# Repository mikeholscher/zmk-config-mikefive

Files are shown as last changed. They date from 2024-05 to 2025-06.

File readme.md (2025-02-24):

# mikefive, a Kailh PG1316S keyboard

Welcome to my repo about my mikefive keyboard! 

It's wireless and five millimeters thick. Here's a picture of it:

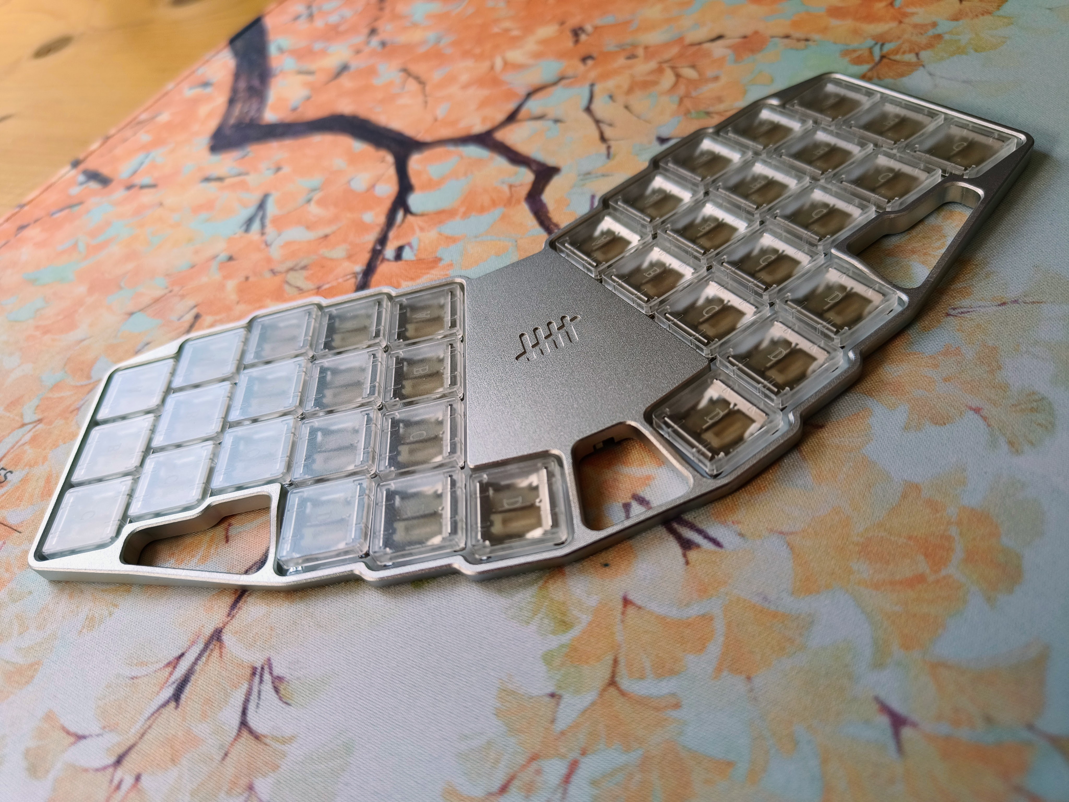
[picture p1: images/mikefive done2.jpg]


The keyboard above is completely custom-designed around Kailh PG1316S switches. 
These switches I got unexpectedly offered by Kailh when ordering other stuff in early 2024. 
I think this build sparked some ultra-low enthusiasm in the community as multiple shops are now carrying them. Go build! 

## Where are the files?!

Sorry. You won't find files or info to build the keyboard yourself here, yet. 

You will only find the ZMK config files for the custom shield, my current keymap, and a custom json for [ZMK Keymap Editor](https://nickcoutsos.github.io/keymap-editor/). 
Most commits here will probably be me updating my keymap :)

Maybe I was a fool to show it to the world already, while I only built a single prototype. 
Because, like with most first prototypes, I found stuff that needs to be improved before other people start building. 
Next to that, another unexpected opportunity arose, which I will definitely scream from the rooftops about when it's more concrete...

## Devlog

Find all noteworthy project developments here. 

I will update this page when there is news, and post on r/ergomechkeyboards or r/olkb too.

### 2025-02-24 I uploaded the keycap files!
You can now find the keycap STEP files in the [keycap folder](/files/custom-keycaps). Don't forget to read the readme in that folder.

### 2024-10-26 I made custom keycaps for the PG1316S switch!
You can read all about in this [Reddit post](https://www.reddit.com/r/ErgoMechKeyboards/comments/1gcibfw/custom_keycaps_for_the_ultralow_kailh_pg1316s/), where I made a write-up in the comments if you would like to read about all the details. I resin-printed them myself. The CAD models will be on this site soon so everybody can print them, after I verified they also fit well using when ordering them from a commercial print service.

Small update: I received a small batch of my keycap prints from JLC, but they have more play to them than my own, and I don't want people to be disappointed when printing my caps. Tolerances are very small on this cap and switch combination. Stay tuned for updates! I am working on it.

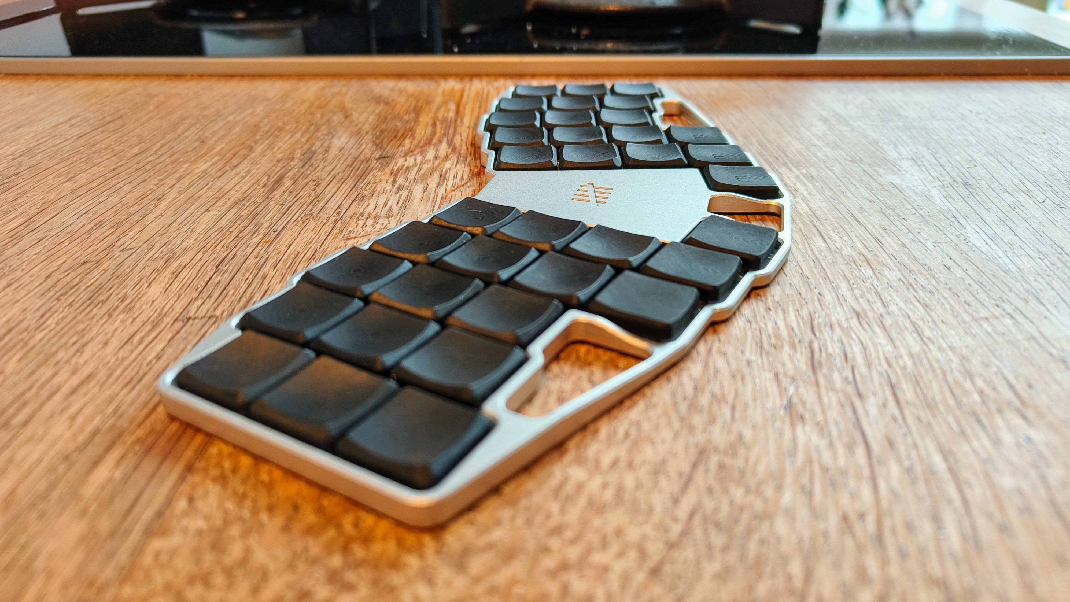
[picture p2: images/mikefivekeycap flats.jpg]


### 2024-07-18 Introducing the even smaller PG1316M, 3D CAD also available!
I was informed by a Reddit member about the existence of the PG1316M. Yes, an M instead of an S at the end. This is a lower height switch, often used as Fn-row keys. I don't have a physical sample yet, but based on the keycap size in CAD, I think the keycap size will be around 16x12mm, compared to the 16x16mm PG1316S. I learned from Kailh, that these will also become available! Again, I am free to share the 3D CAD file, really awesome! You can also find the PDF spec sheet in the folder, as this M version does not seem to be on their website yet. I think I will soon add the KiCad footprint for the PG1316M as well!

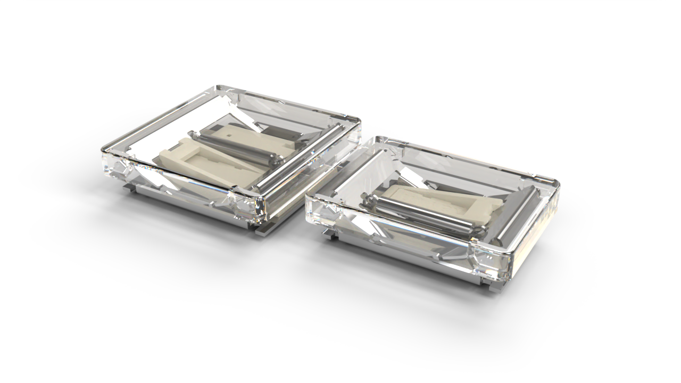
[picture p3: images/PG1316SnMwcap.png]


### 2024-07-16 3D CAD file of PG1316S switch now available!
I received a lot of questions about the availability of a 3D CAD file of the switch and keycap of the PG1316S. Well, I asked Kailh if I could share, and I can! You can find it in the [files folder](/files). I also used the switch model to render images like below and select matching materials before I had the prototype produced. NOTE: This is the original 3D CAD file I received from Kailh. I noticed the switch dimensions are spot-on and the inside of the keycap is too but the outside of the keycap is too small. In reality, the keycap is 16.25mm vertically and 16.05mm horizontally.

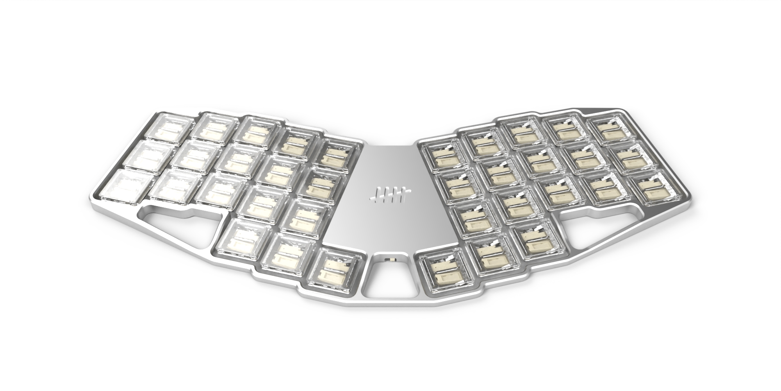
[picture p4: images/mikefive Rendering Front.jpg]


### 2024-06-19 Lighter switches are installed!
I received the lighter prototype switches from Kailh and installed them in the mikefive. They feel much better and are a lot more quiet. I uploaded a small video update on [Reddit](https://www.reddit.com/r/olkb/comments/1djruze/new_lighter_kailh_pg1316s_switches_in_the_mikefive/). I am planning on making an extensive video update soon, with much more news to share!

### 2024-05-26 KiCad footprint now available!
I received a message from someone that was able to order some switches, and asked if I could share the footprint. The KiCad 8.0 footprint is in the [files folder](/files), and looks like this:

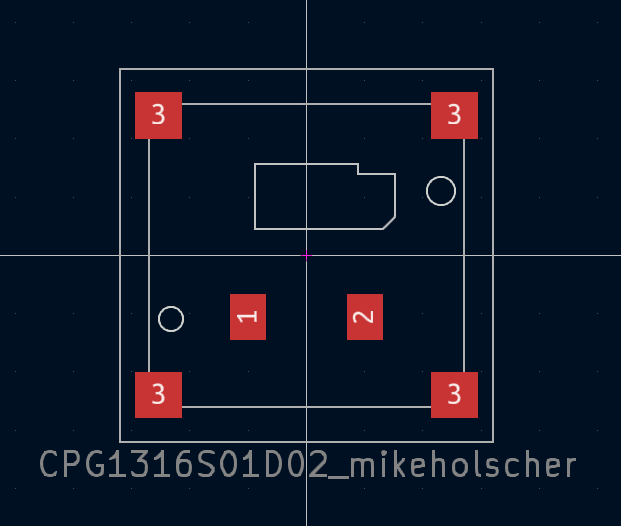
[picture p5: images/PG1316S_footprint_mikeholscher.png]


Some explanation:
- The outer, biggest square is the 16x16mm keycap.
- The slighty smaller square is the switch 'frame' size.
- The two small circles are holes for the allignment pins on the switch.
- Pads 1 and 2 are the switch pads.
- Pads 3 are the SMD mounting points for the switch frame. NOTE: I placed vias in these pads in the PCB to give the switch a more secure connection to the PCB. (I hope) this way the switch connects to both sides of the PCB instead of only the top layer. I connected all pads 3 to GND in the switch diagram and schematic.
- The weird shape in the top half is the available space under the switch for components. I placed my diodes there in the mikefive.

Kailh also made a [product page](https://www.kailhswitch.com/mechanical-keyboard-switches/kailh-ultra-thin-notebook-switch.html) for the PG1316S switch, including [spec sheet](https://www.kailhswitch.com/uploads/15927/files/CPG1316S01D02-data-sheet.pdf?rnd=569) where I based the footprint on. I did some further measurements on the physical switch to complete some details such as the space underneath.

### 2024-05-06 kbd.news reposted!
kbd.news was kind enough to [repost](https://kbd.news/Mikefive-a-Kailh-PG1316S-keyboard-2366.html) my Reddit post on their website!

### 2024-04-28 Hello world :)
After completing the build on Wednesday 24th of April and working with it for a couple days, I decided to make a [post](https://www.reddit.com/r/ErgoMechKeyboards/comments/1cfg3vr/mikefive_a_kailh_pg1316_keyboard/) on r/ergomechkeyboards. 
It became a really long write-up, as I wanted to share as many details as possible.
Thank you all for your flattering replies! They really gave me energy to continue the project and make sure the keyboard will eventually get in the hands of people that want it.

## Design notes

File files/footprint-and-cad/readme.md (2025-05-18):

This space will get some more info about footprints later. 

Note:
I have had good experience with using 0.8mm vias in the switch contact pads and 0.6mm vias in the switch mounting pads. I have the feeling they are easier sucked down to the PCB. 
Some solderpaste will leak onto your hotplate if you put big vias in the pads, and I was warned about possible damage to the hotplate, but so far it seems easy to clean on my Miniware MHP30 and PCB with IPA.
The original specsheet also shows holes in the pads, which might be for a reason. On mikefive I skipped these vias to get a fully contact free bottom, which is also worth something.

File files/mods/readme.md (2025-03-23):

# Kailh PG1316S mods
You just built your first PG1316S keyboard. You spent hours and hours making all of your switches work on your PCB, and then you start typing. Dang, these switches sure feel and sound different. And then you find out your PG1316S doubles as a musical rhythm instrument when you shake it.

No worries. I got you covered. All you need to make your fresh PG1316S keyboard sound and feel a lot better is here :)

I spend a good chunk of time trying to solve these issues by making custom 3D-printed keycaps, which work well to eliminate rattle and improve the sound. But dimensional tolerances are very tight, and these caps are not the easiest to print. I wanted a quick solution that could be used to improve the stock switch and keycap without much effort. The result was two 'papermods', which anybody with a pair of scissors and a piece of paper can do. 

## Papermod1
The papermod1 is just a rectangular piece of paper measuring 13.8x12.7mm that eliminates the play between PG1316S switch and the stock keycap and causes the rattle. This makes the switch feel more robust and silent. Just put it under the keycap as shown in the image, and BAM, instant improvement. Try different thicknesses of paper or even different materials and see what you like best.

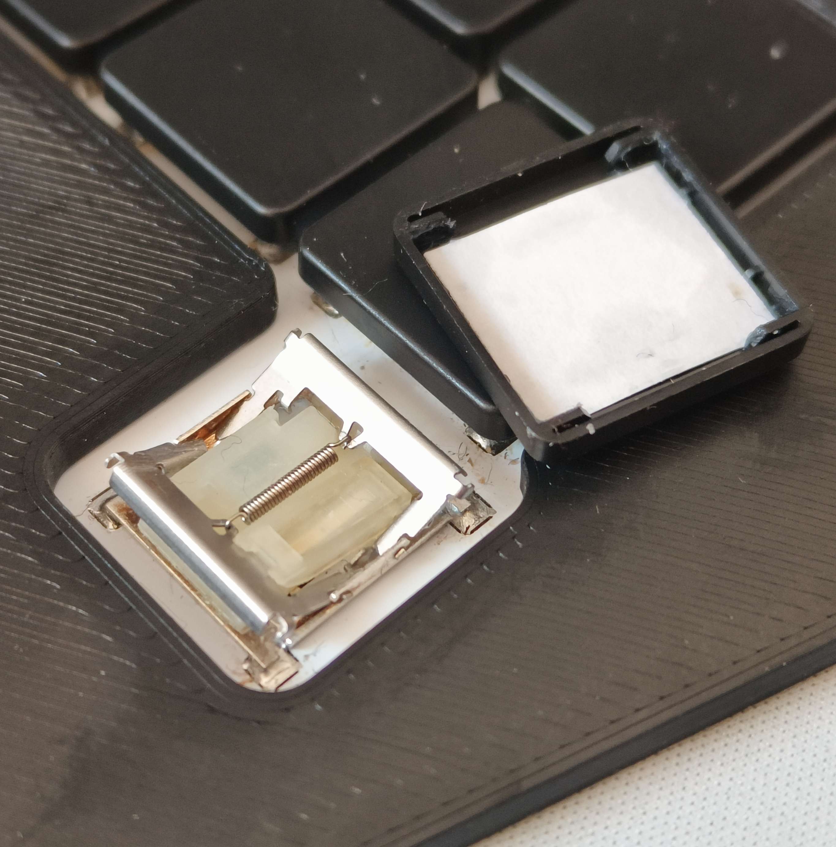
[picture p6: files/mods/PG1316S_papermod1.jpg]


## Papermod2 (with VIDEO!)
Papermod1 is cool, but it still has a relatively hard bottom out. Which you might like, or not. Papermod2 prevents the hard bottom out by reducing the stroke by the height of 2 pieces of paper (about 0.2mm) attached to the sides of papermod1. Both bottom out and sound are softer because the metal pieces inside the switch don't clash with each other anymore. 

You can download the papermod2 [video](PG1316S_papermod2.mp4) (.mp4 file) above by clicking on it and downloading the raw file using the button in the top right on the next screen. The video shows how to fold papermod2 and demonstrates the difference in sound between (1) stock, (2) papermod1, and (3) papermod2.

## Papermod cutting template!
There is a PDF with cutting template for both papermods in one, the source InkScape file, and a DXF of a separate papermod2 piece if you have a lasercutter at hand. Just download, print, cut, and try. Try one keycap first. It's easy and fast.

## Note on different stock color keycaps!
I tested these papermods on the BLACK stock keycaps. I have experienced that the transparent keycaps (I have) have a slightly tighter fit. You might need a thinner piece of paper to prevent having a too tight fit that can block the motion of the switch.

## Legends and colors using the stock transparent keycaps!
Putting paper below the transparent keycaps does not look very nice. Unless you use some colored paper. And put some legends on it to learn you fresh new layout! Because who uses QWERTY nowadays? Not you right? RIGHT?! OK. Then we are cool.

## Lubing the switches and keycaps
Yes, for science, I lubed these switches and keycaps. Every hinge that moves or parts that slide on each other were given a minimal amount of Krytox 205g0 using a tiny brush. And well, it helps in making the switches feel smoother, it really does. Most keyboard switches are factory lubed a bit, so why not these? I also managed to eliminate a squeaky noise coming from one of the switches this way. It's a relatively expensive and time-consuming mod, but far from the time you need to lube box switches found on other keebs. When you feel ready for a zen task just take off the keycaps, apply lube, repeat, and enjoy ;)

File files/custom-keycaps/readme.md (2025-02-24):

# Custom Keycaps: READ ME FIRST!
### I STRONGLY ADVISE NOT TO HAVE THESE FILES RESIN PRINTED AT A COMMERCIAL PRINT SERVICE!
I have successfully printed these keycaps on my OWN resin printer. I tuned all dimensions for a good fit using my OWN printer. After tuning them to perfection I ordered them at JLC and received keycaps with a very bad finish and fit, even different fits between individual keycaps. 

Especially for resin printing, many variables influence the dimensions of the printed part: slicing orientation and settings, material properties, shrinkage, washing time, curing intensity, abrasive post-processing, and who knows what. Since these keycaps require very precise dimensions to have a tight fit on the switch without rattle but not too tight to prevent the switch from getting stuck, resin printing somewhere else is therefore far from ideal. 

## Well, what should I do with these files then?
Ideally, print them on your own printer. Start with a couple and tweak the scale or even individual part dimensions to get a better fit. I have heard testers get good results from scaling the part 101%, for example. I printed them in the orientation shown below, and I only supported the outer (orange-marked) edge to minimize/eliminate cleanup. The right image is how I oriented them for an FDM print on our Bambu X1C at work using 0.08mm layer height, and it worked surprisingly well!

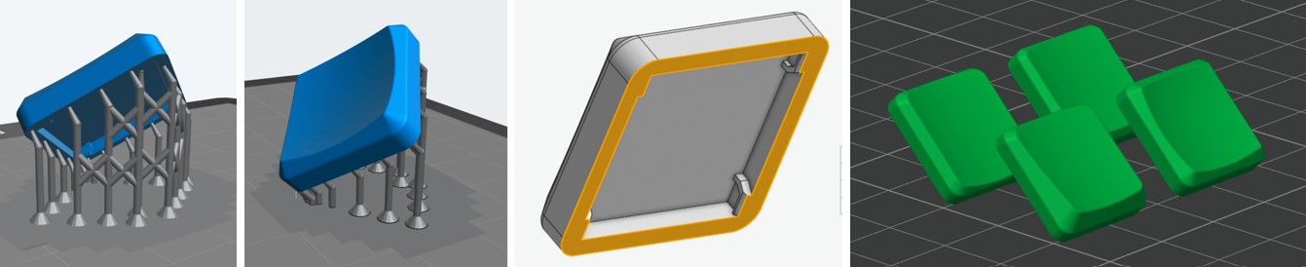
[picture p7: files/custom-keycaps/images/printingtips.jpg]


I was able to print a nice batch on my relatively small build platform of a our Anycubic Photon S printer, a relatively old printer, but still works pretty well.

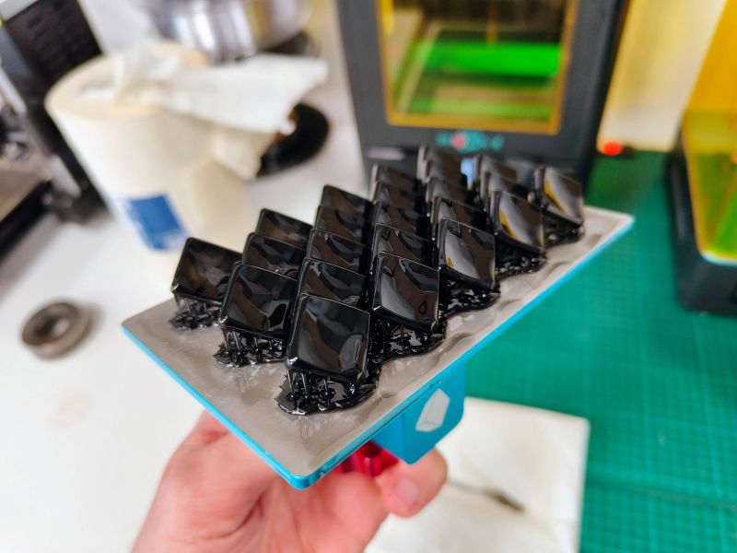
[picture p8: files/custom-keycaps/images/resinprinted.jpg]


## What if I don't have a printer?
MJF printing should be a better option as all of those machines are from the same manufacturer (HP) and use proprietary materials and software. They are known to produce very repeatable part dimensions from wherever you have them printed. If you can live with the slightly grainy and grippy texture, I would advise going with MJF. Make sure to mention in the instructions to place all caps in the same orientations. Preferably the 45 degree angle to prevent layer lines.

# Two types of keycaps
### Normal type
This is a design similar to MBK caps which are very popular in the low profile community. For the thumbs there is a modified version with a less sharp bottom edge.

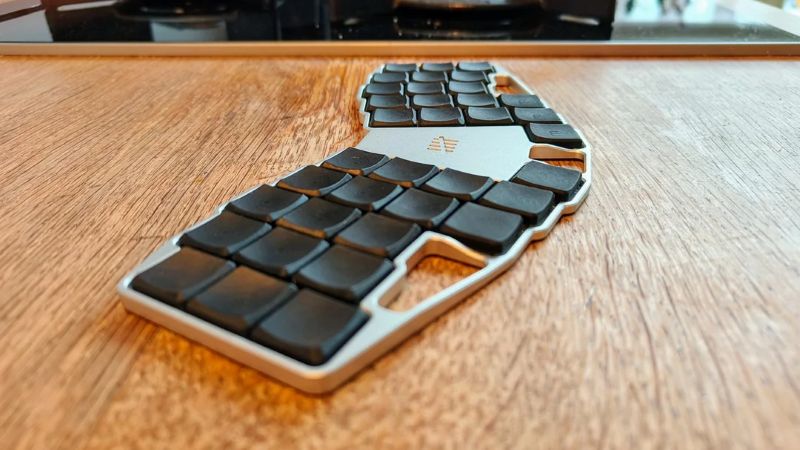
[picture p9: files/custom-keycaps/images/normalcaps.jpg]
)

### Keywell type
A popular concept nowadays. The thumb keycaps are the same as the top and bottom row.

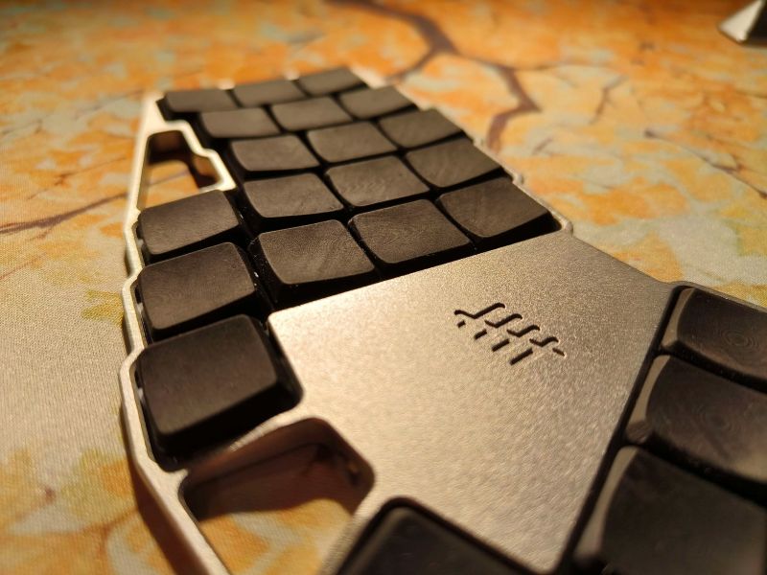
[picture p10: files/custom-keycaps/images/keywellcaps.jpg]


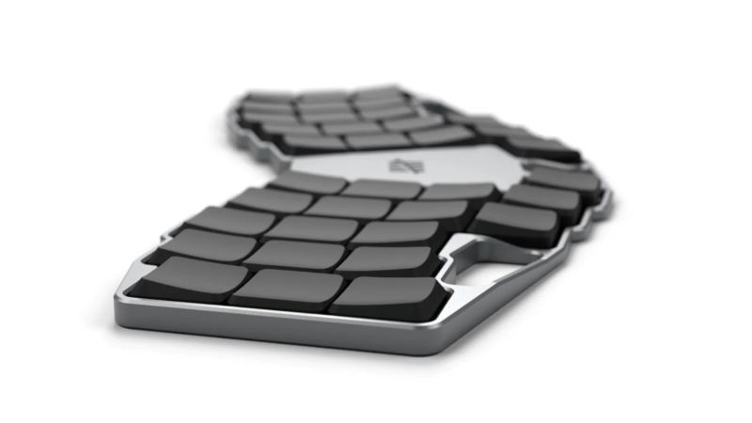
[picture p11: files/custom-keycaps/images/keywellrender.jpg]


## Can I use these models for production and sale?
Yes. But you must leave a mention of this repository/author to end users.

## Can I modify, fork, post (or whatever) these models?
Yes. Rules are the same. Give a credit to the author.

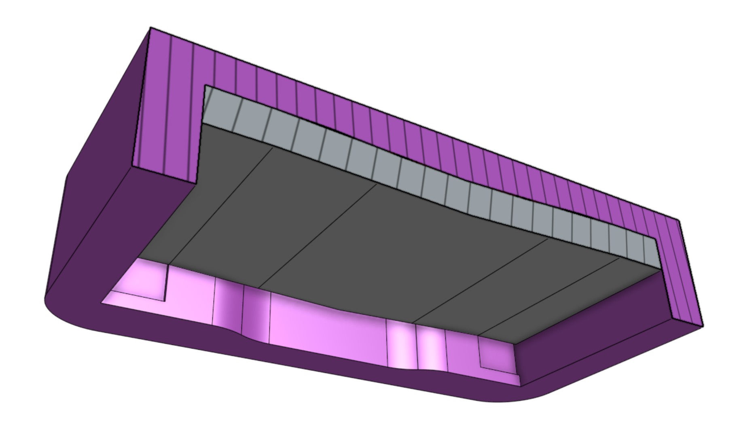
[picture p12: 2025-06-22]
files/custom-keycaps/images/mikeholscher_PG1316S_keycap_convexfoammod.jpg

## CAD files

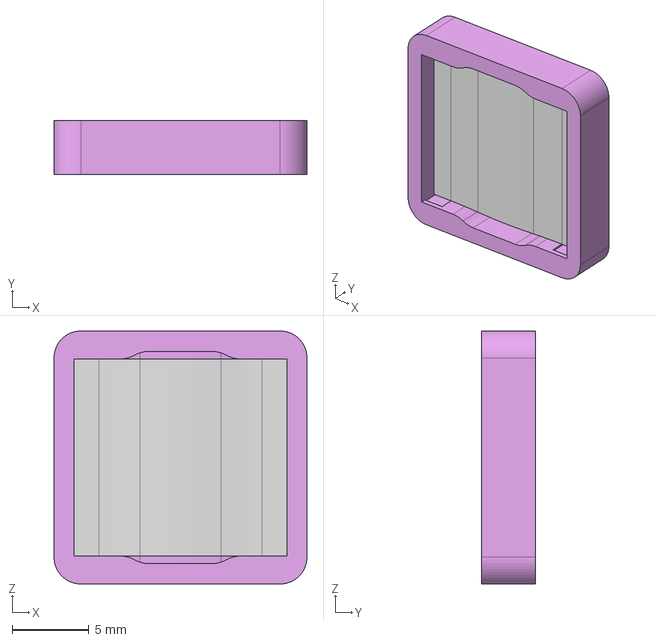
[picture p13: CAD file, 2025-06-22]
files/custom-keycaps/mikeholscher_PG1316S_keycap_convexfoammod.step
16.5 x 3.50 x 16.5 mm

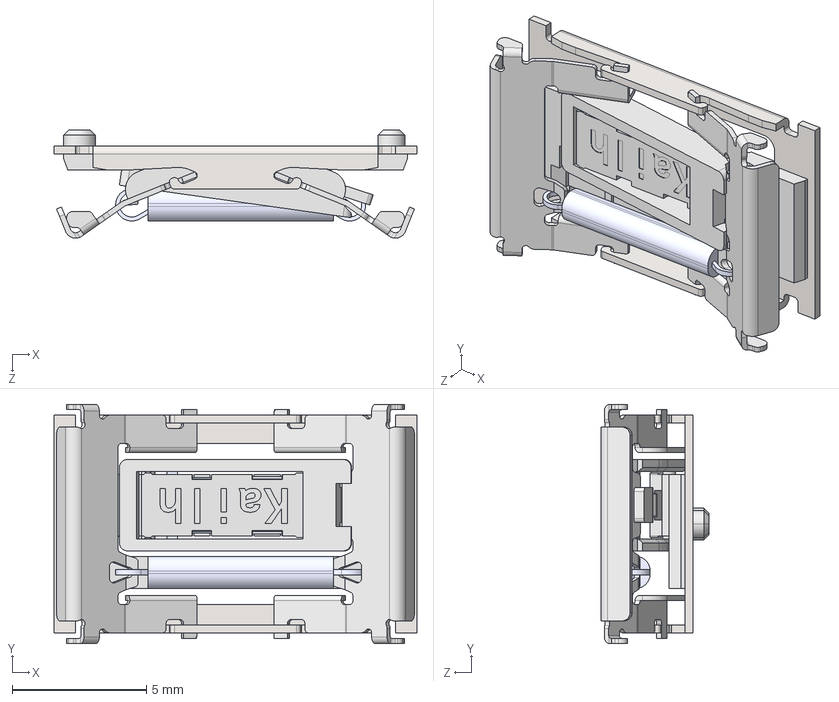
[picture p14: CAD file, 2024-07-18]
files/footprint-and-cad/PG1316M--装配体.STEP
13.5 x 8.90 x 4.03 mm
1316S-基座卡件
PG1316S-價釱
驱动杆
す算殤-B璃
嶺銅
PG1316S-动接触片-带触点
PG1316S-静片-带触点
す算殤

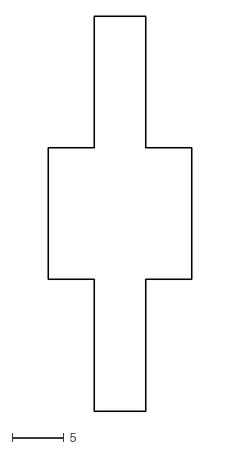
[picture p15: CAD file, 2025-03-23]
files/mods/PG1316S_papermod2.dxf
13.8 x 38.1

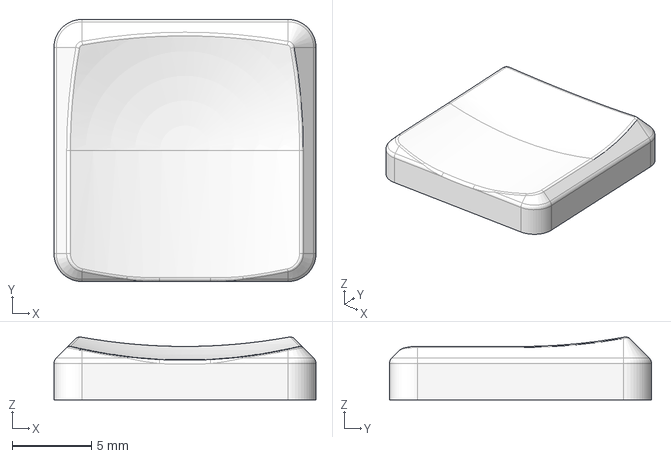
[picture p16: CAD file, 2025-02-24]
files/custom-keycaps/mikeholscher_PG1316S_keycap_normalthumb.step
16.5 x 16.5 x 3.96 mm

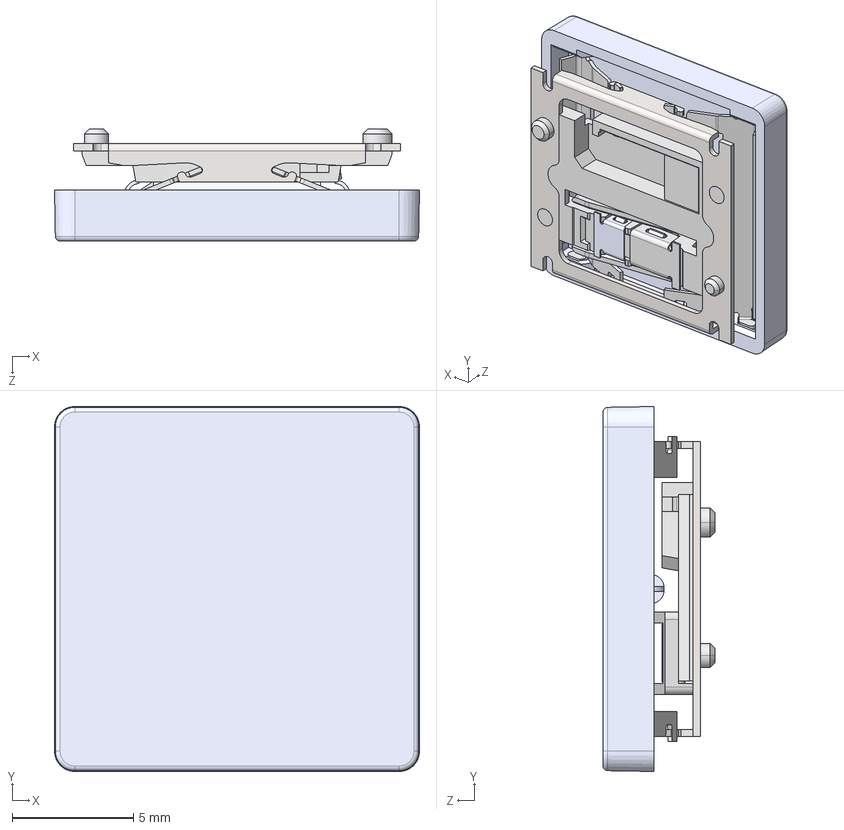
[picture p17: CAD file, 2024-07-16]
files/footprint-and-cad/PG1316S--装配体.STEP
15.1 x 15.1 x 4.63 mm
1316S-基座卡件
PG1316S-價釱
驱动杆
す算殤
嶺銅
PG1316S-动接触片-带触点
PG1316S-静片-带触点
す算殤-B
瑩簽

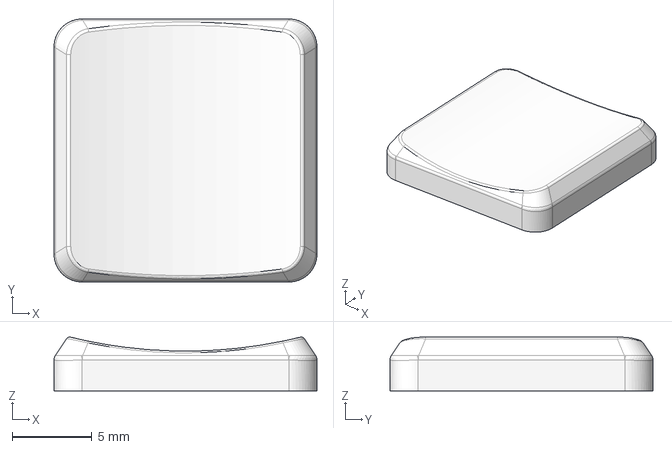
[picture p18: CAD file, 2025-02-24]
files/custom-keycaps/mikeholscher_PG1316S_keycap_keywellcenter.step
16.5 x 16.5 x 3.38 mm

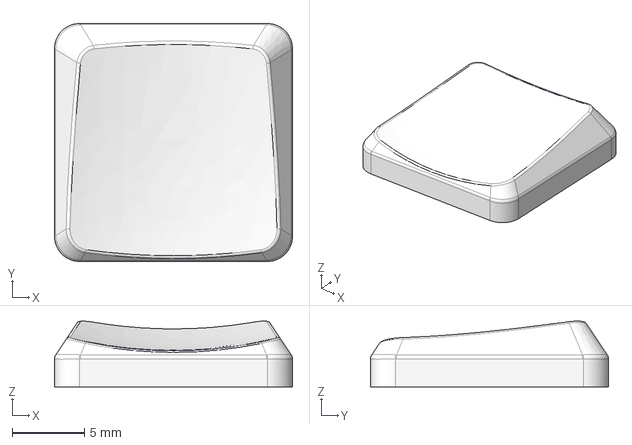
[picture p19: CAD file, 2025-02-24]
files/custom-keycaps/mikeholscher_PG1316S_keycap_keywellangled.step
16.5 x 16.5 x 4.56 mm

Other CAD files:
files/custom-keycaps/mikeholscher_PG1316S_keycap_normal.step

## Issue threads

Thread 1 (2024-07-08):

Switch model

jrhe, 2024-07-08:
Would it be possible to provide the switch model? It's defined in the footprint as "PG1316S--装配体.STEP"

jedifindtrick, 2025-01-02:
@jrhe Just in case you haven't seen it, the model and other stuff should be available now.

anscarlett, 2025-03-13:
Part is available on JLCPCB, but there's no footprint as yet. Would it be acceptable to upload the files from here?

anscarlett, 2025-03-13:
@mikeholscher Awesome, i'll look out for it. Thanks for your work:)

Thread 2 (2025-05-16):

Center-to-center for switches

qwelyt, 2025-05-16:
Your footprint contains the bigger box to indicate where the cap will be. Is the exact edge of the cap or is there some space?
If I place two footprints besides one another, what would be the proper spacing for these switches? MX has ~19, chocs ~18, but these ones? What would you say the minimum distance should be with your footprint?

mikeholscher, 2025-05-16:
Good question. The stock keycaps are 16x16mm on spec, but more 16.2mm in reality. I guess you can go as low as 16.5x16.5mm for center to center spacing without tolerance and slack issues, but I went for 17x17mm on all my boards as this is a standard called CFX spacing, and felt good on a mockup. My custom keycaps are printed slightly bigger than stock caps (16.5x16.5mm) to get them a little tighter while using CFX spacing, and this works well. Does this answer your question?

qwelyt, 2025-05-16:
Perfect answer, thank you!
And with that I would suggest another box in your footprint. One that is either 16.5 or 17mm. That way when you place footprints you can put them as overlapping on the box edges and make placement a breeze (or one can just place the footprints relative it's neighbor and get the correct spacing, but where is the fun in that).

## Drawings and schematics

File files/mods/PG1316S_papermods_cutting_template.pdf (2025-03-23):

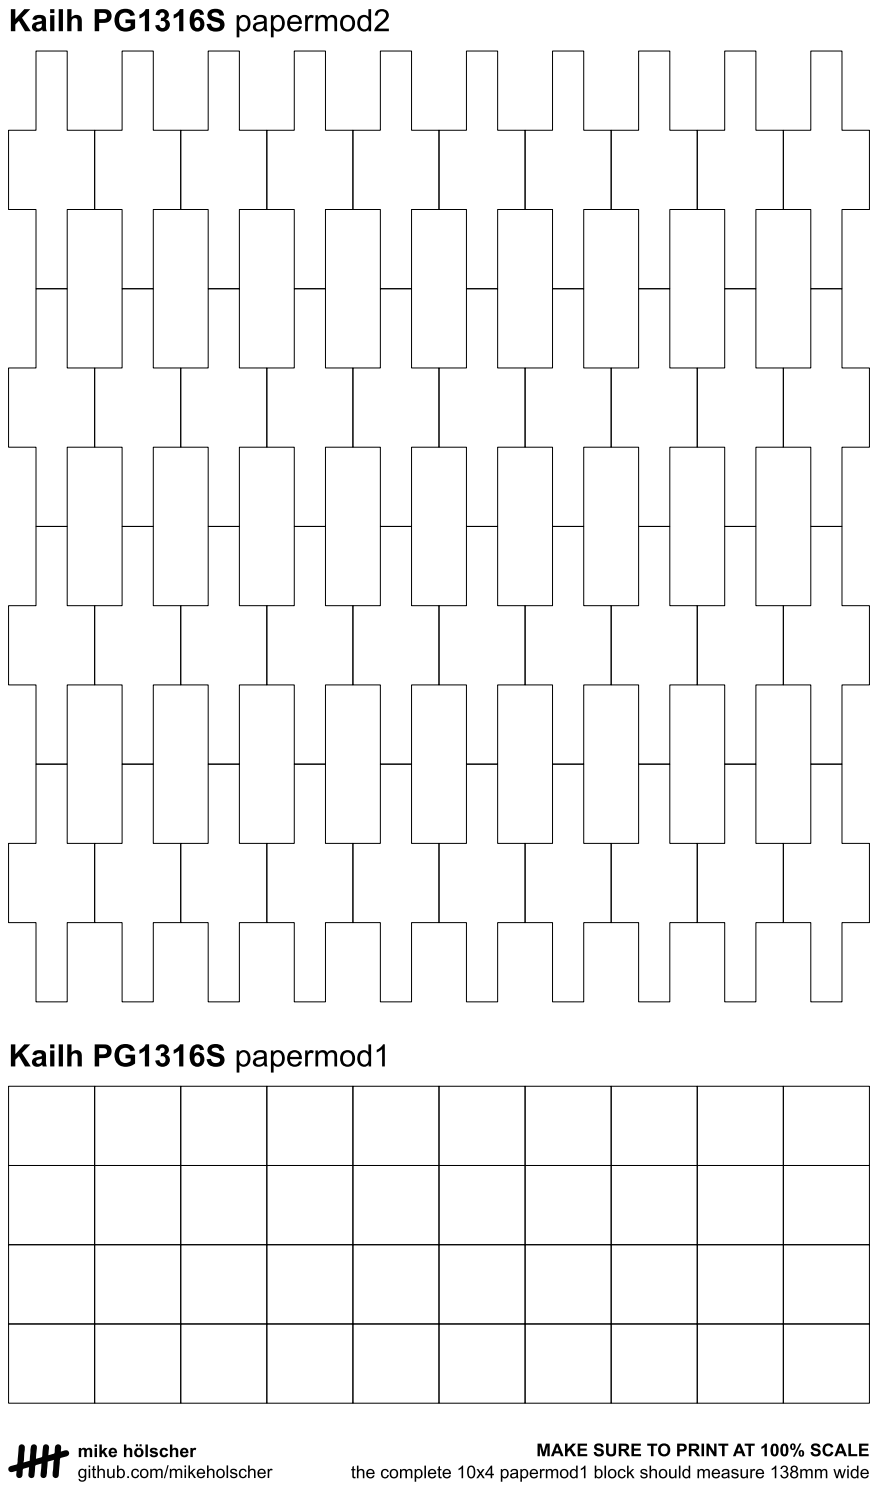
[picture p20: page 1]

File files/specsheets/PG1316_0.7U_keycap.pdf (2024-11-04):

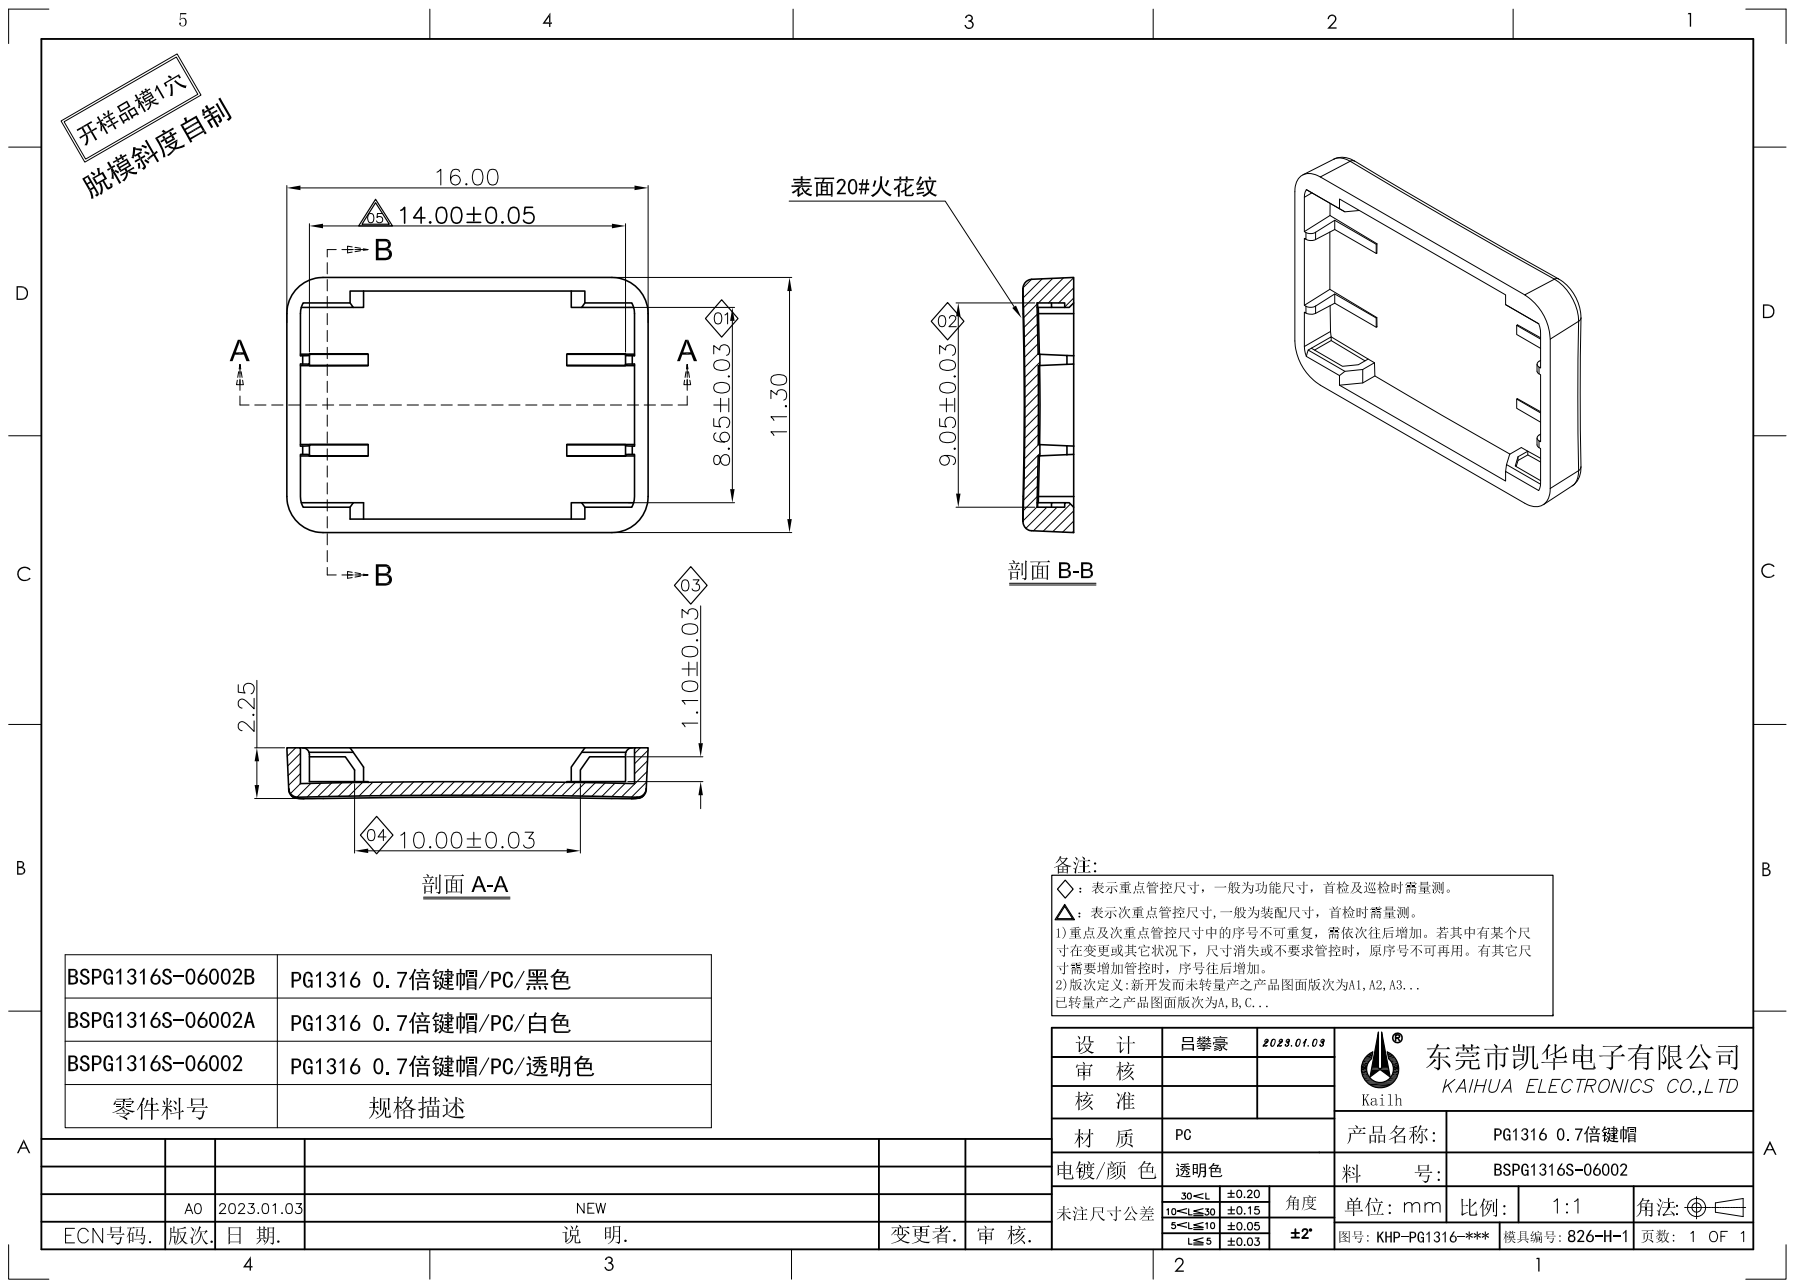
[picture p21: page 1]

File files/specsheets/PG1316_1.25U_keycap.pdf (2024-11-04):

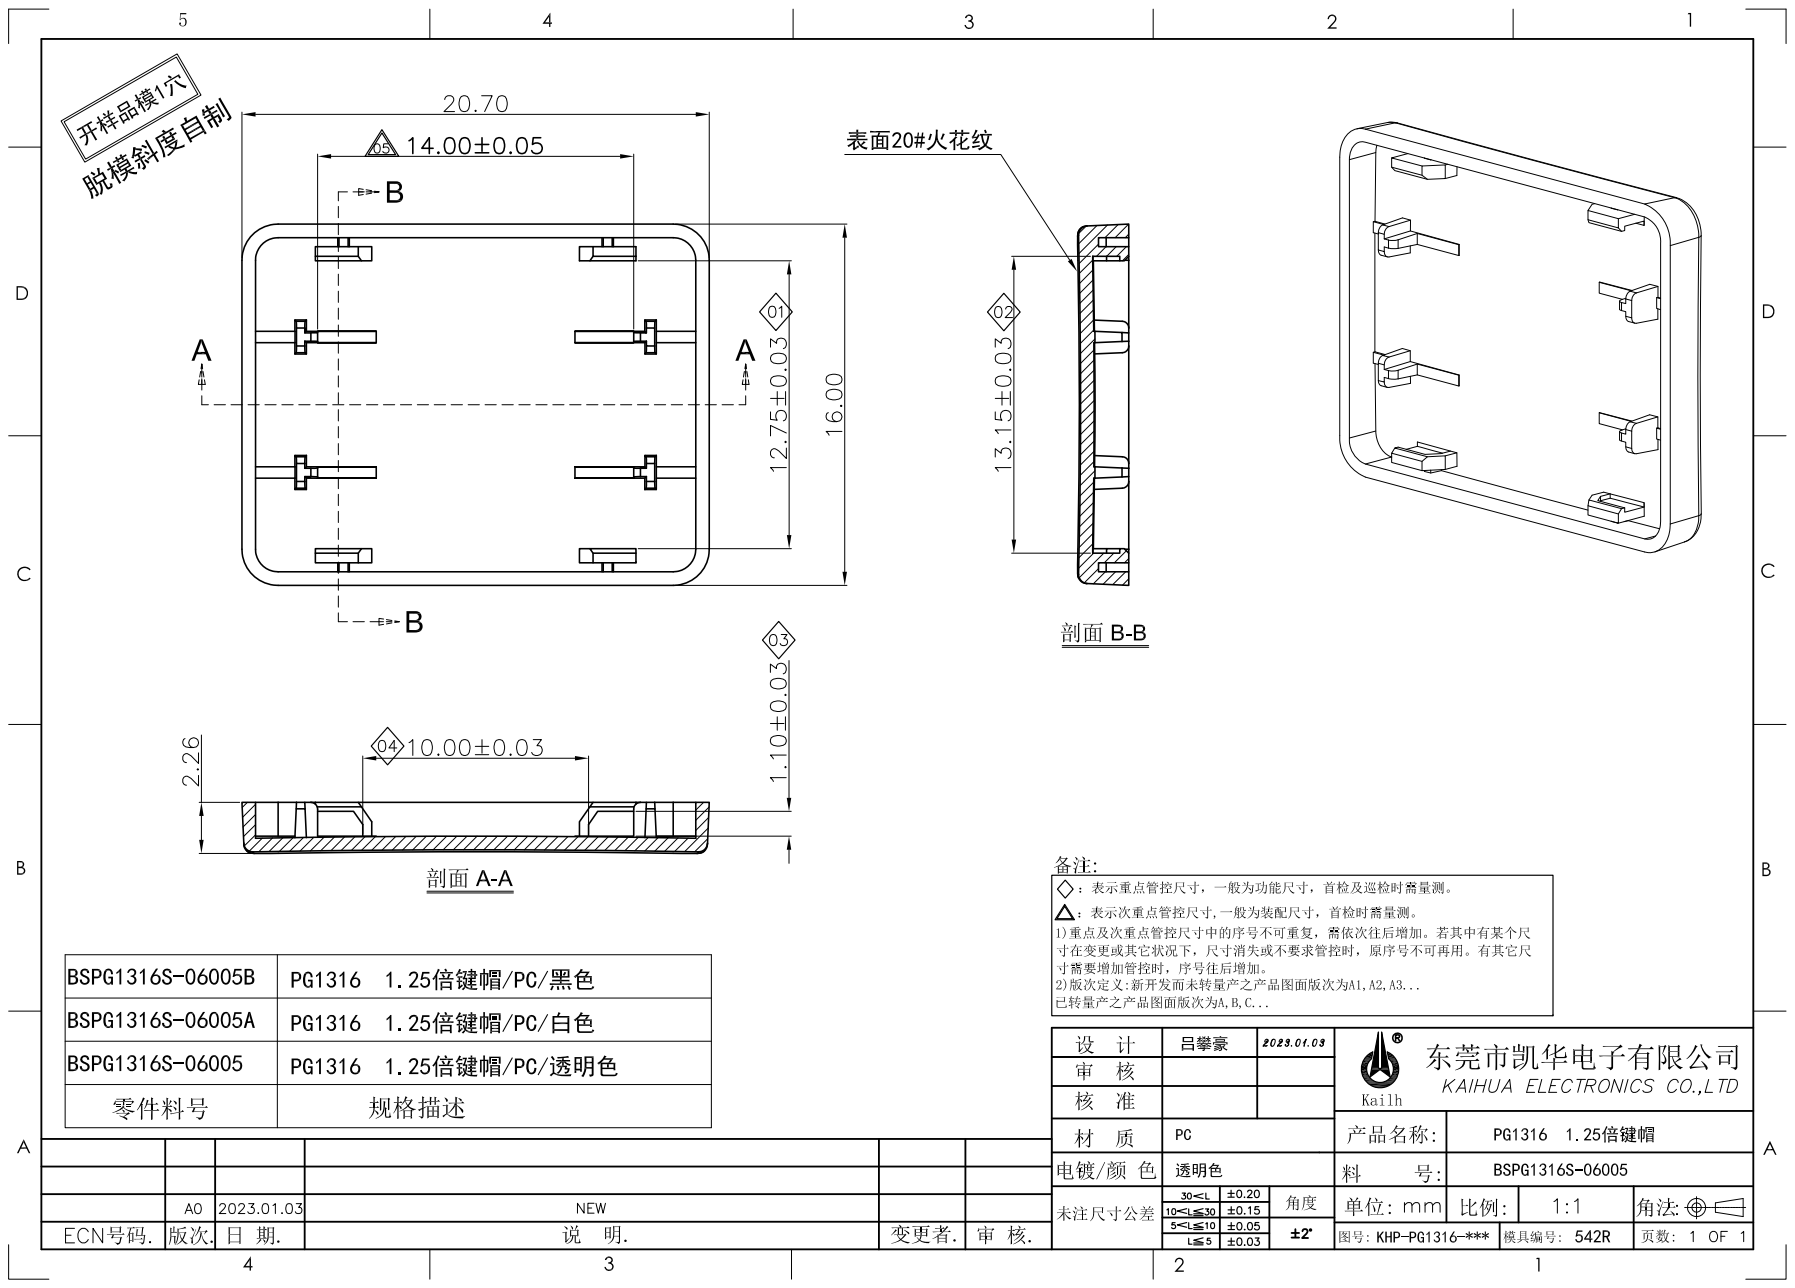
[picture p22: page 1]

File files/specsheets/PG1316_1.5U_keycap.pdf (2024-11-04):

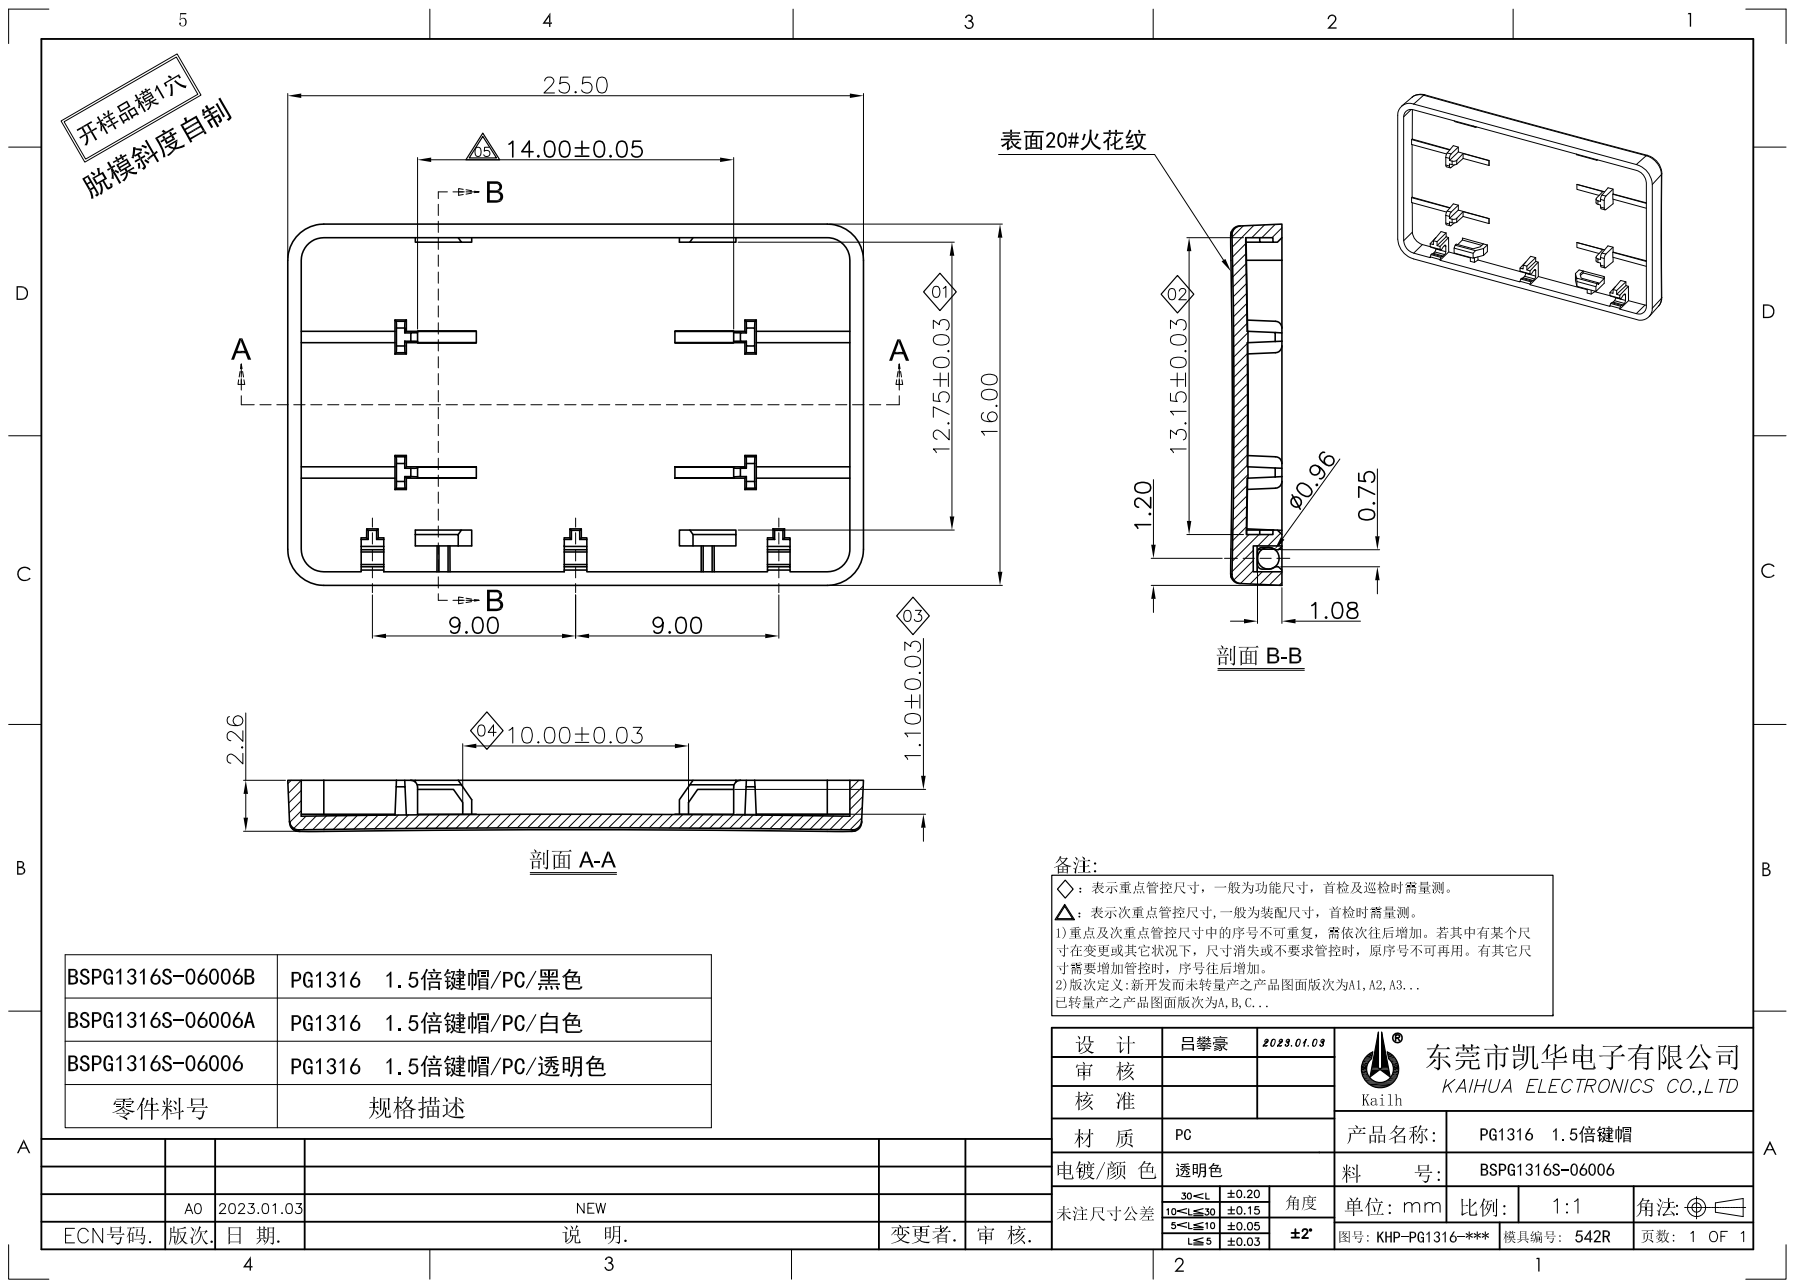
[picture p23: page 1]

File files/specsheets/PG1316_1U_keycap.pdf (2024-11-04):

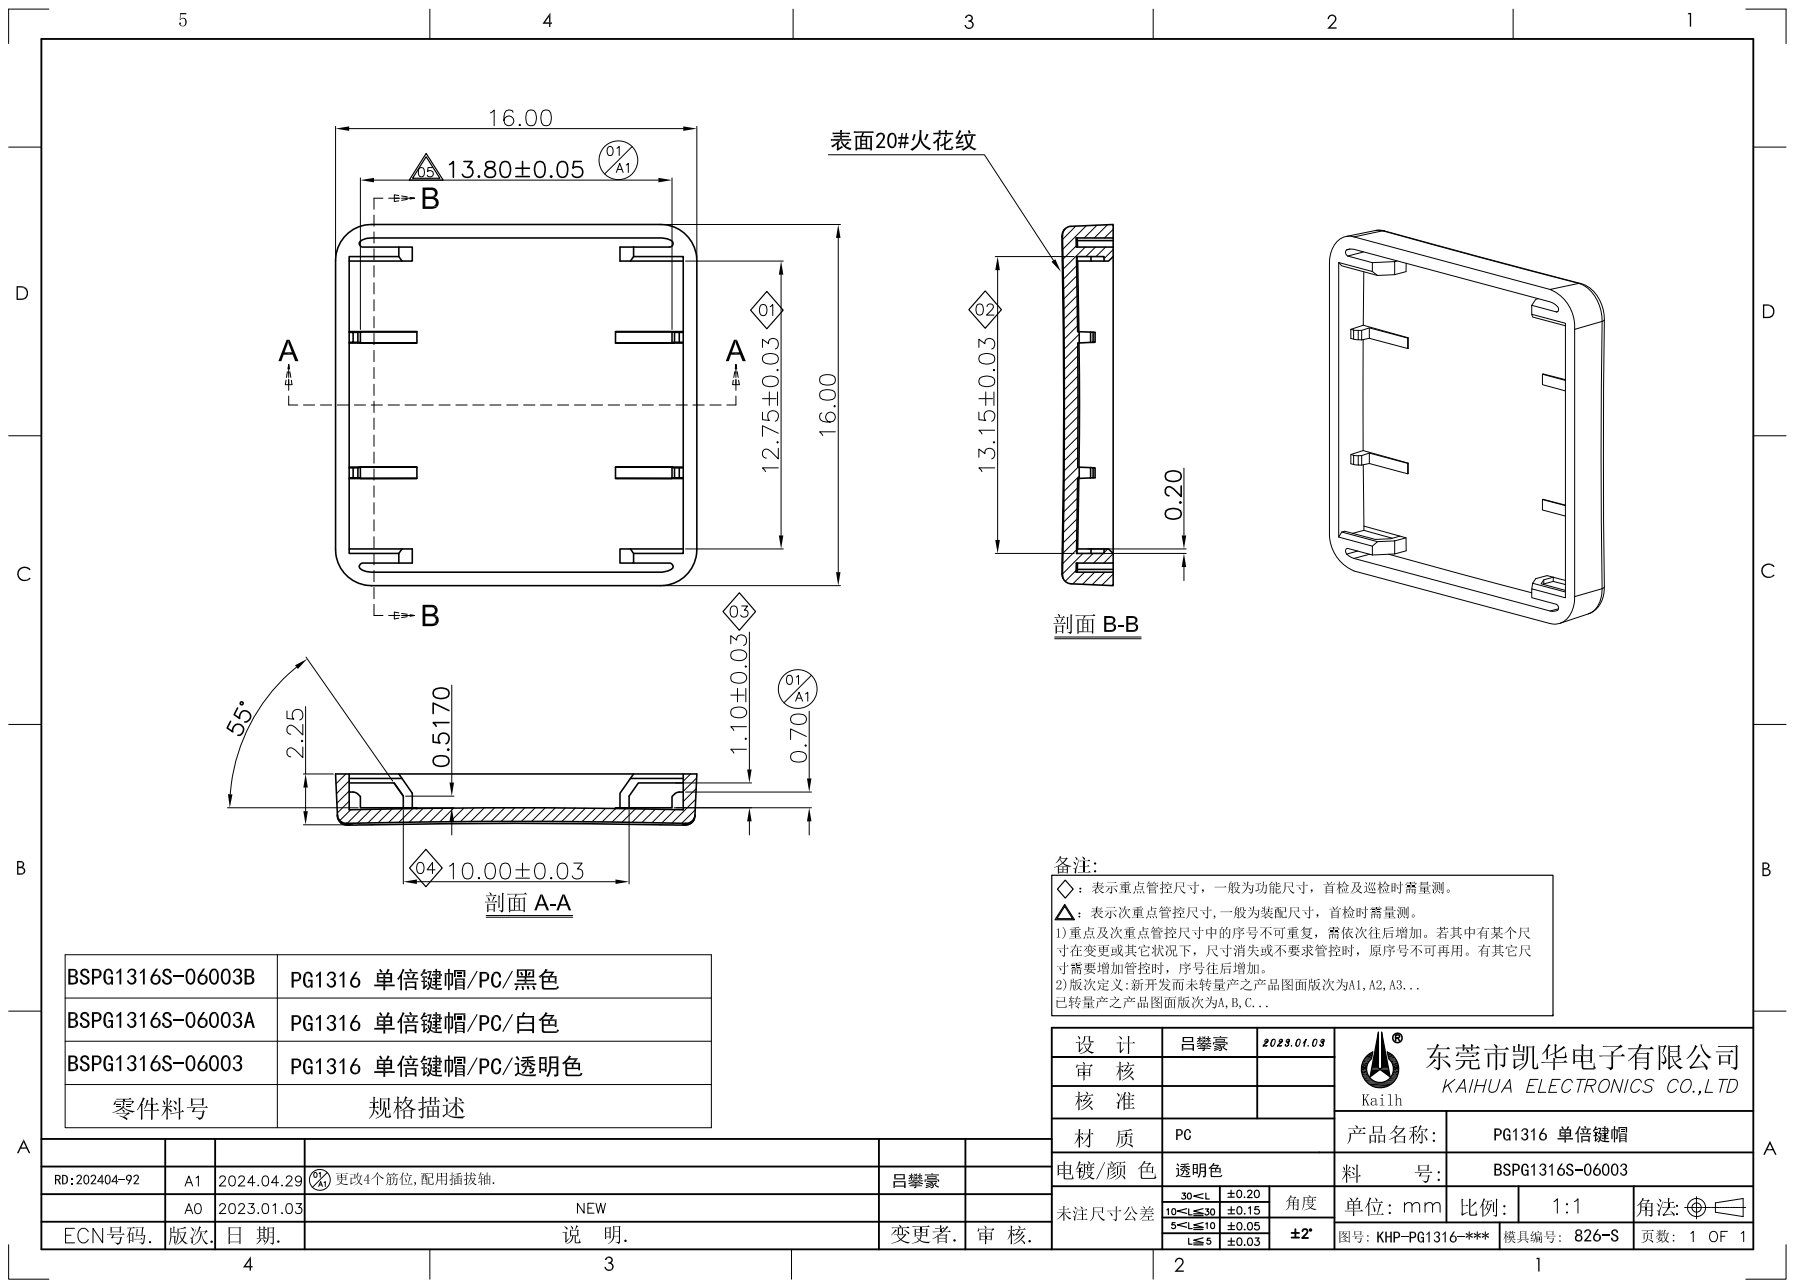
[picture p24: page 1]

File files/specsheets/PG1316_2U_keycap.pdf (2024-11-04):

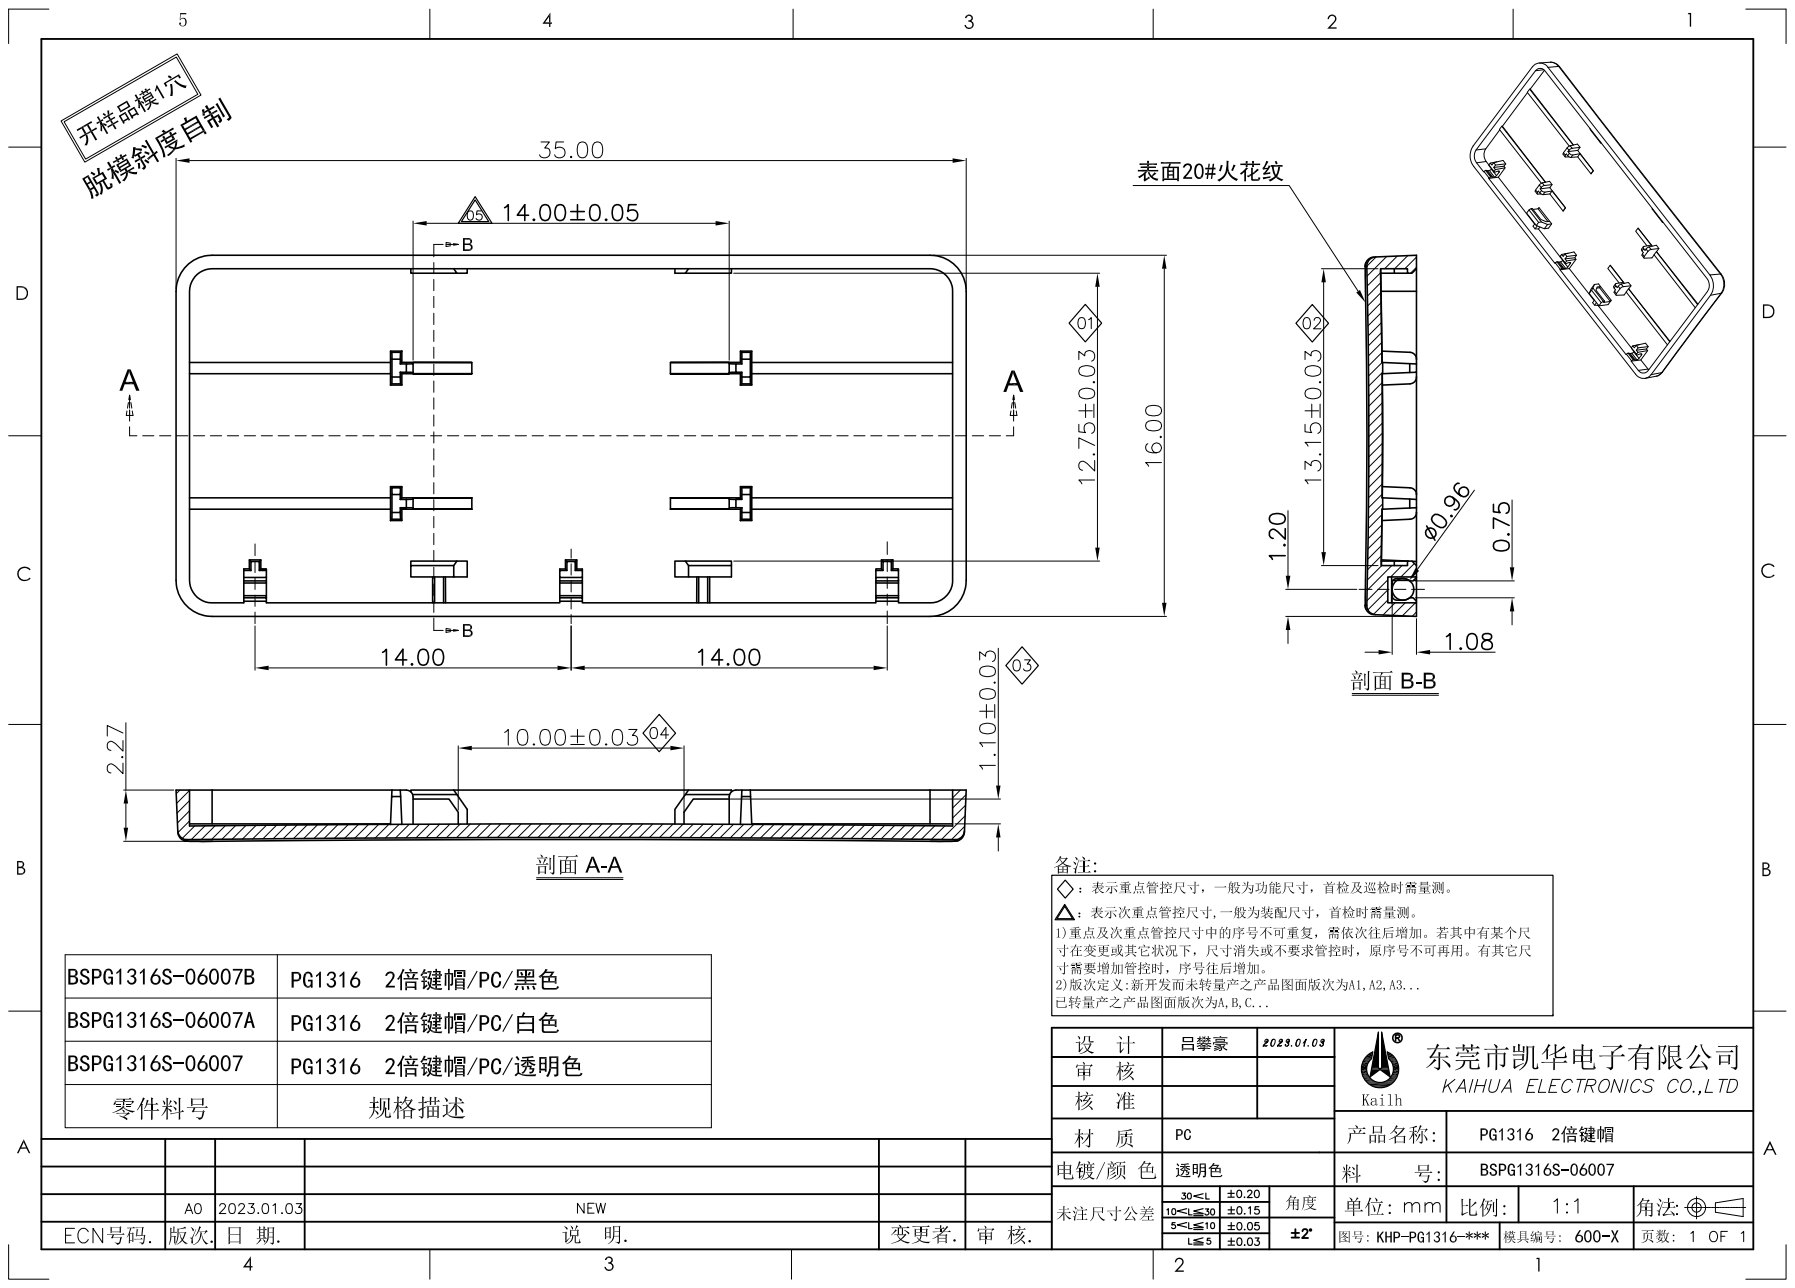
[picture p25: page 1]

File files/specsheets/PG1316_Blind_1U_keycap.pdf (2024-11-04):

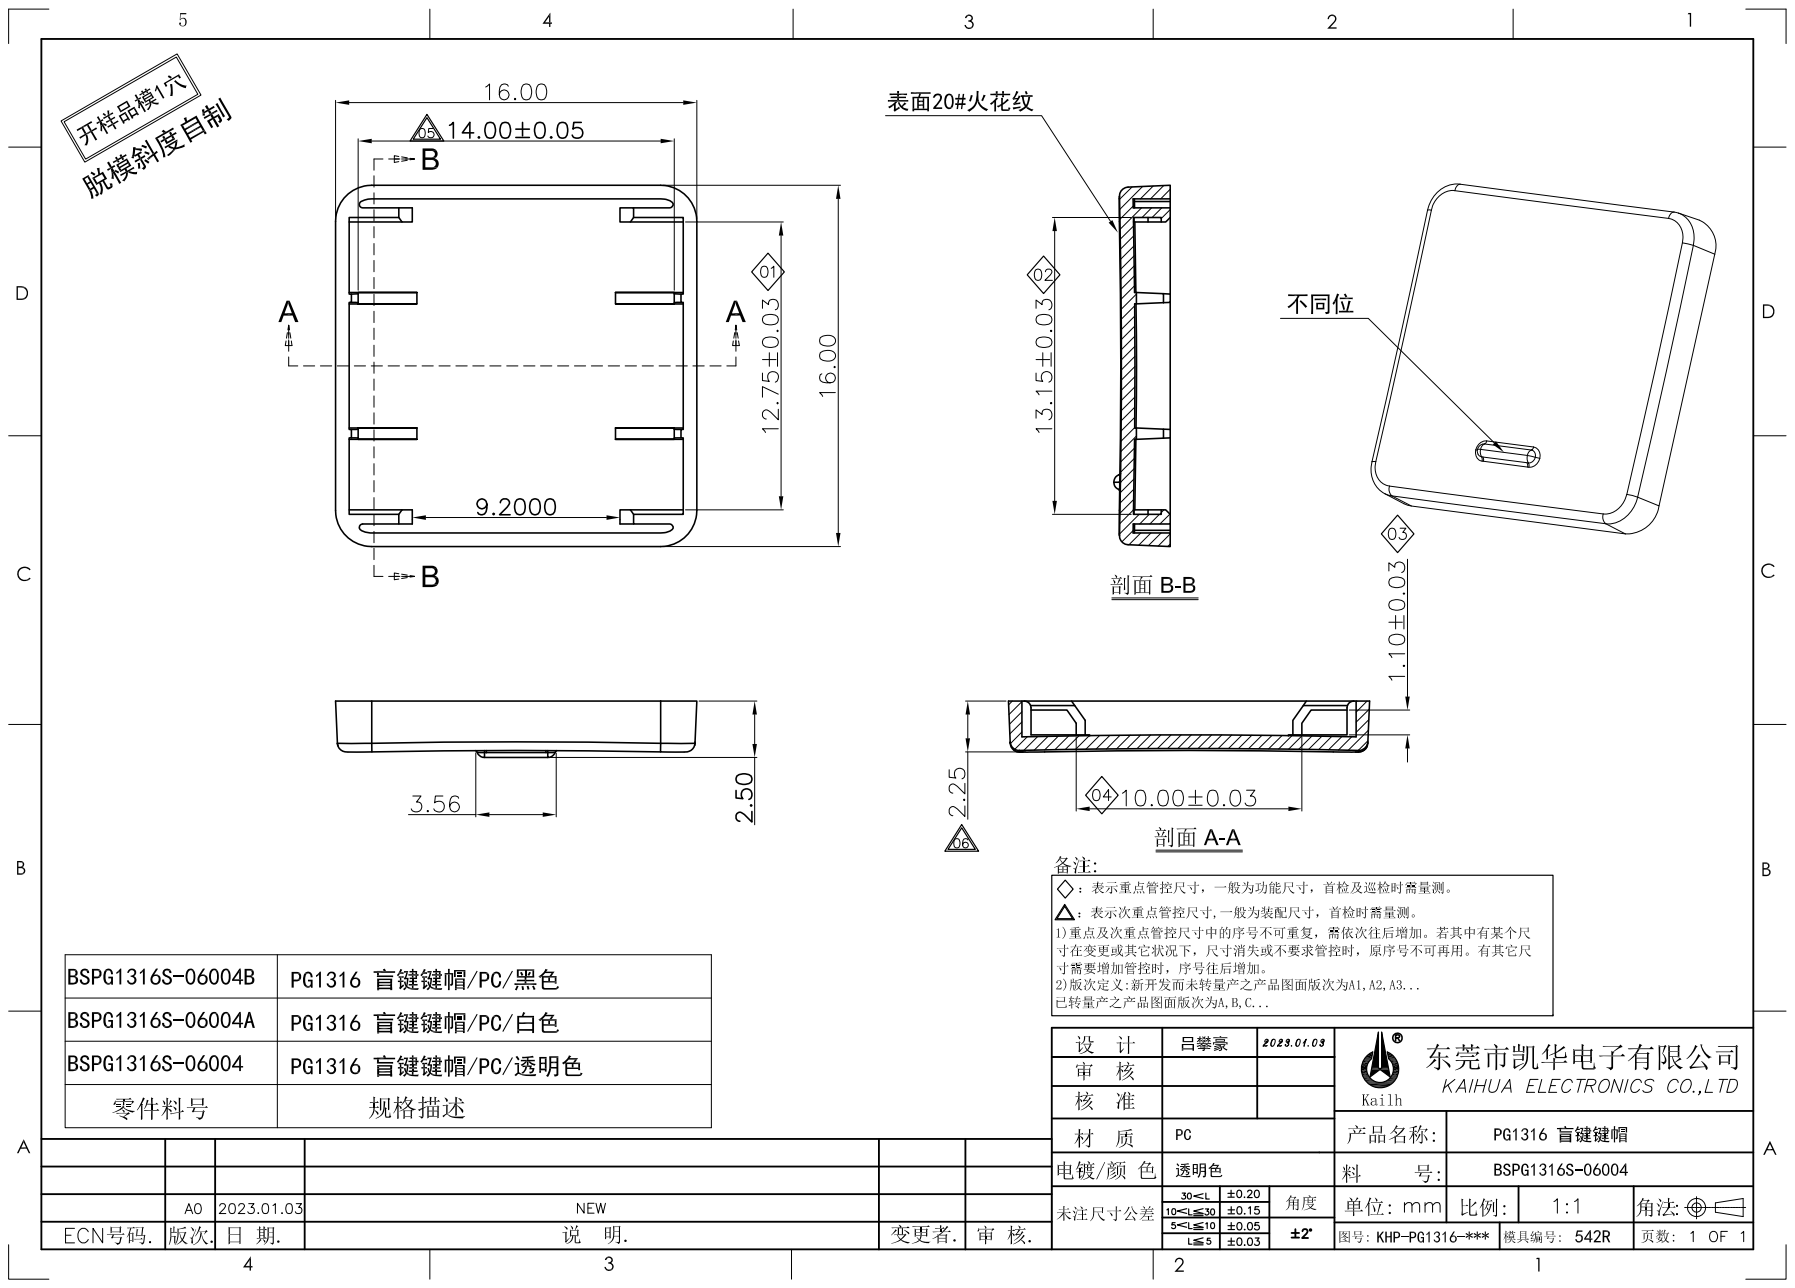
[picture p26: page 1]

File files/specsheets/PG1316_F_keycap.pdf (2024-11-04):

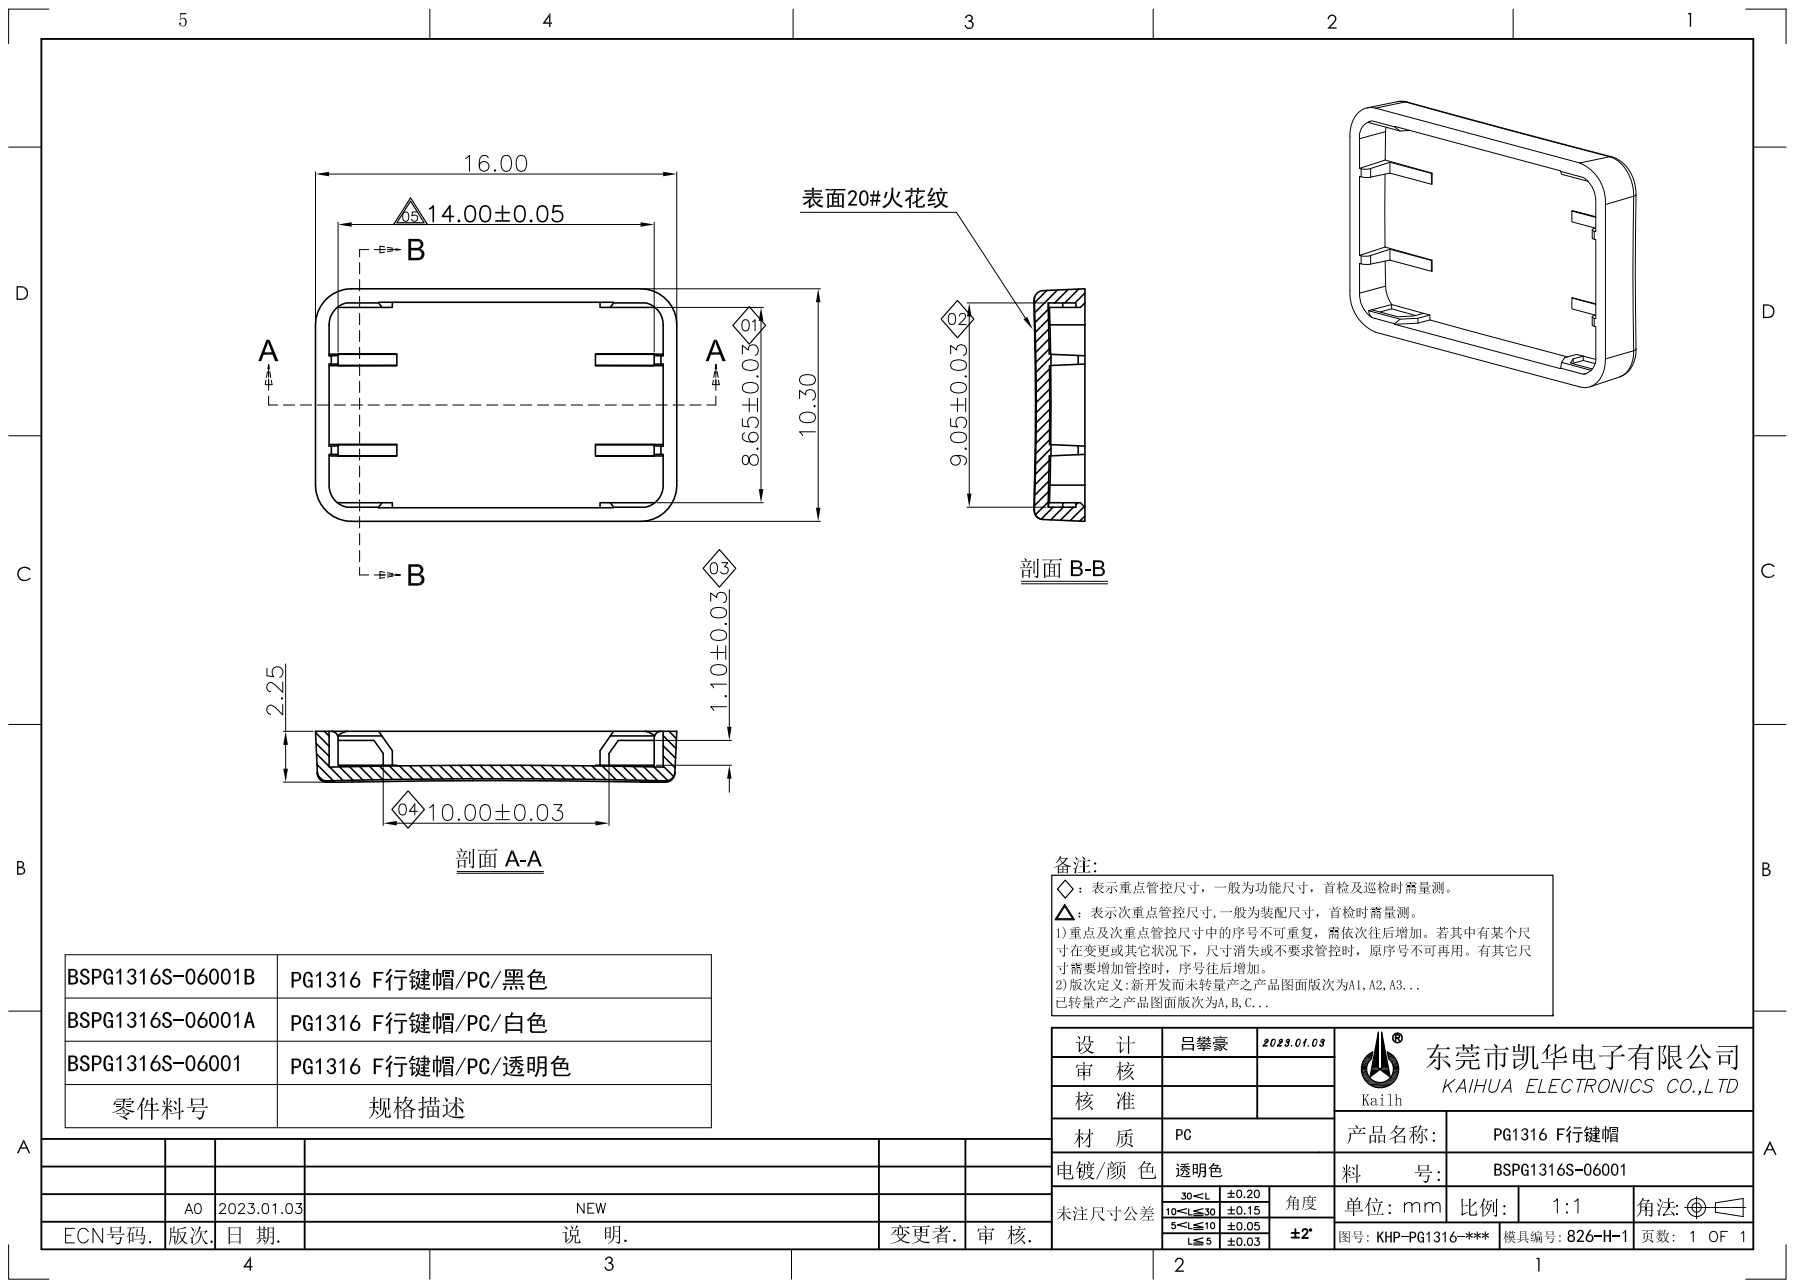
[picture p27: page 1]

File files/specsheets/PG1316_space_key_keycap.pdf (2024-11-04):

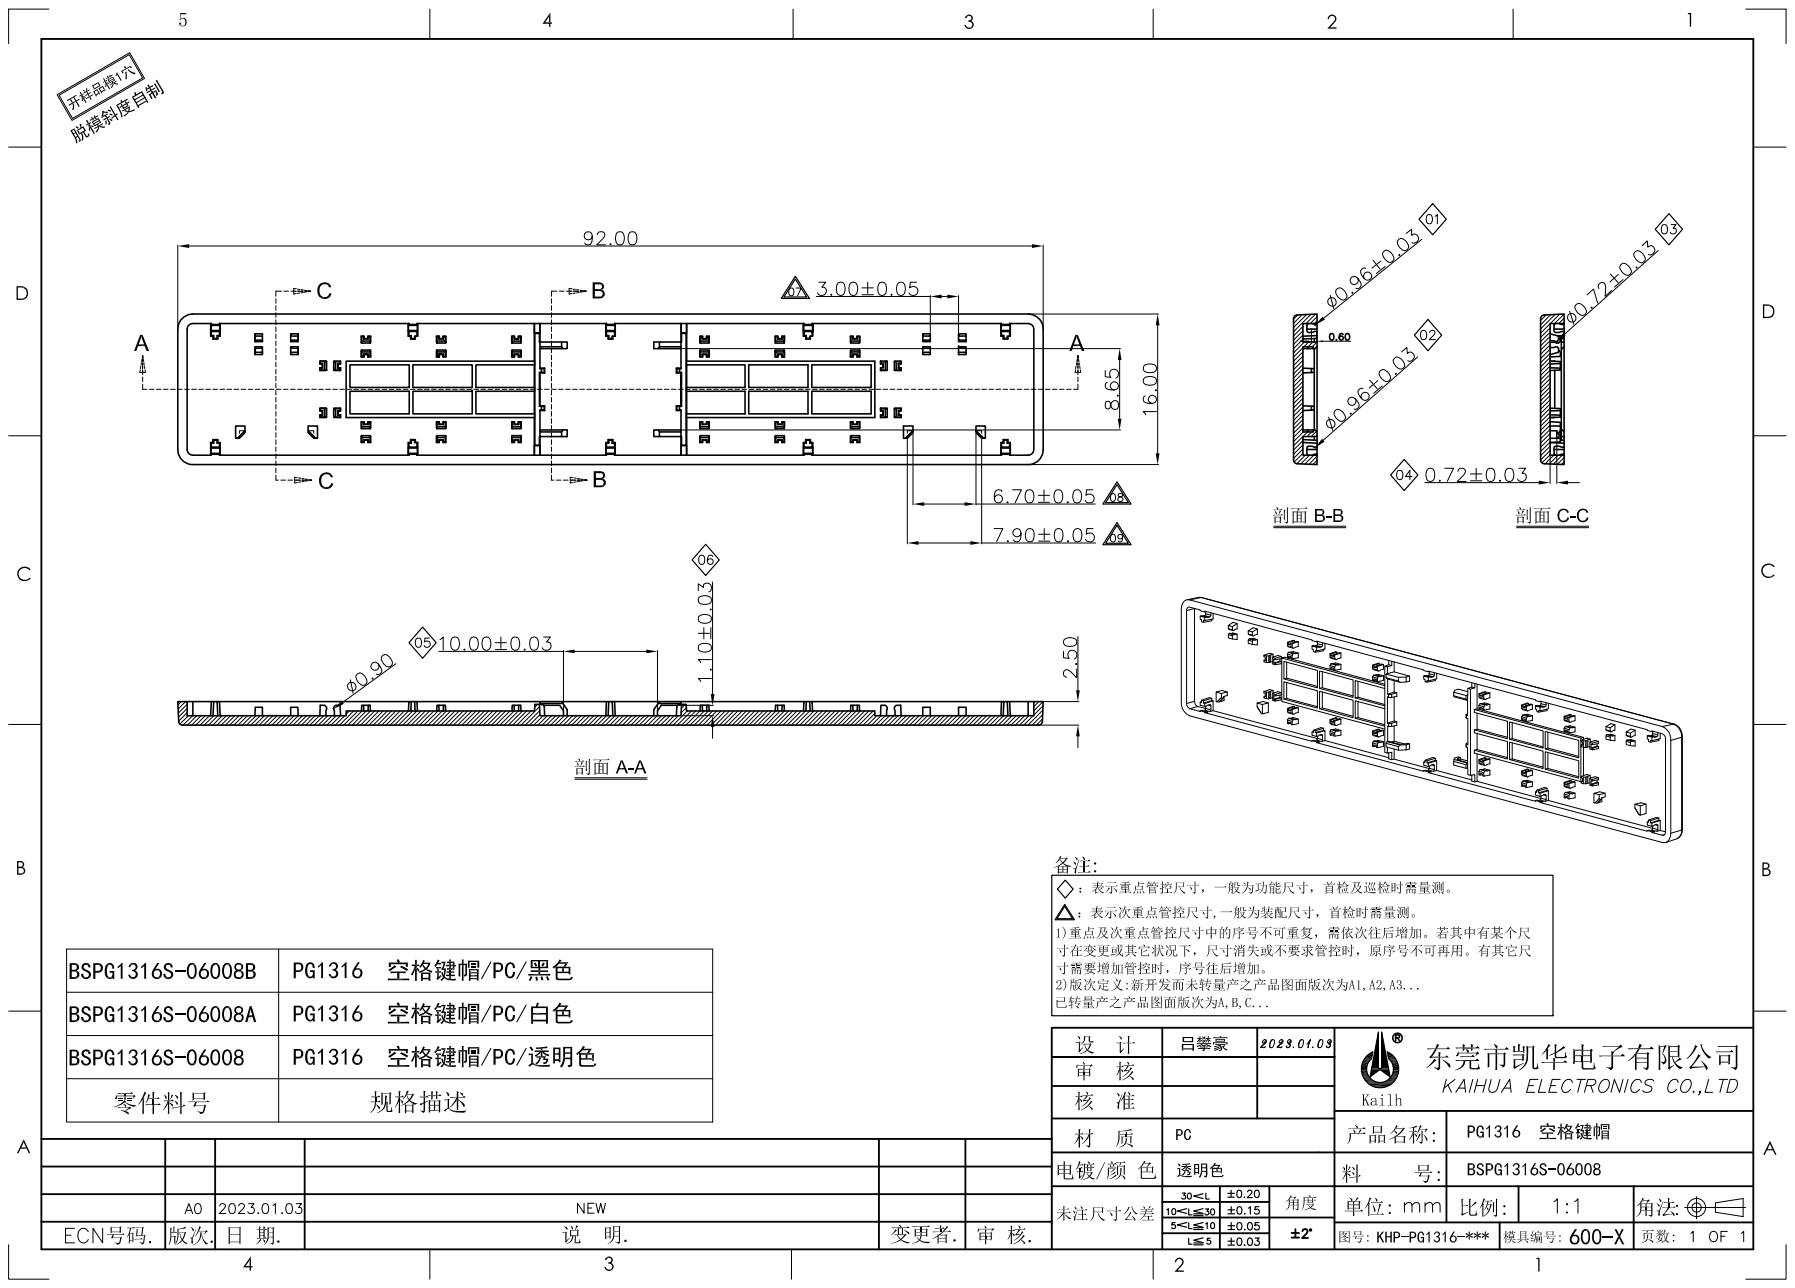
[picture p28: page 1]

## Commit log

2024-05-13 Update mikefive.keymap with led_strip
2024-05-23 added footprint
2024-05-26 footprint readme
2024-07-16 Added PG1316S 3DCAD file
    [PG1316S--装配体.STEP]
2024-07-18 Added PG1316M 3D CAD file
    [PG1316M--装配体.STEP]
2025-02-23 filestructure update
    [PG1316M--装配体.STEP, PG1316S--装配体.STEP]
2025-02-24 added keycap files
    [mikeholscher_PG1316S_keycap_keywellangled.step, mikeholscher_PG1316S_keycap_keywellcenter.step, mikeholscher_PG1316S_keycap_normal.step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]
2025-02-24 added printingtips
2025-03-23 papermods added
    [PG1316S_papermod2.dxf]
2025-05-18 Added 2 footprints
